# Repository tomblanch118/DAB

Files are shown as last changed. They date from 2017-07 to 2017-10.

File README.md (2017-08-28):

# DAB
Electronics schematics, mechanical design and code for the Defuse a Bomb team building activity.

## PCB Version 1.0
There are a few issues with the first version of the PCB, I used A7 and A6 for controlling the RGB LEDs and as the spare io pin. I missed the fact that these pins are analog inputs only (straight to the analog mux). As such version 1 of the pcb requires a few bodge wires from the icsp pins to the leds and buzzer to make it work. As the icsp pins are only used once to burn the bootloader this isnt really a problem and version 2 of the board will fix this. 

You can power the board from an ftdi cable/board however this results in backpowering the 5v regulator/no power to the 3.3v regulator. So far this hasnt proved to be a problem but it probably isnt ideal, YMMV. In future the 5v from the usb bus could be connected to vin but there is a good chance that the 5v regulators dropout voltage will mean that this wont work.

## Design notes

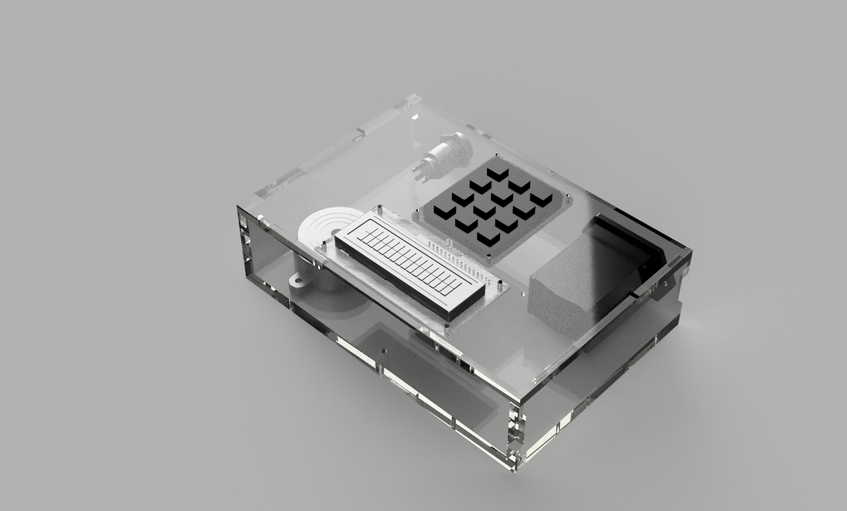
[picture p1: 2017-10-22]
model_render2.png

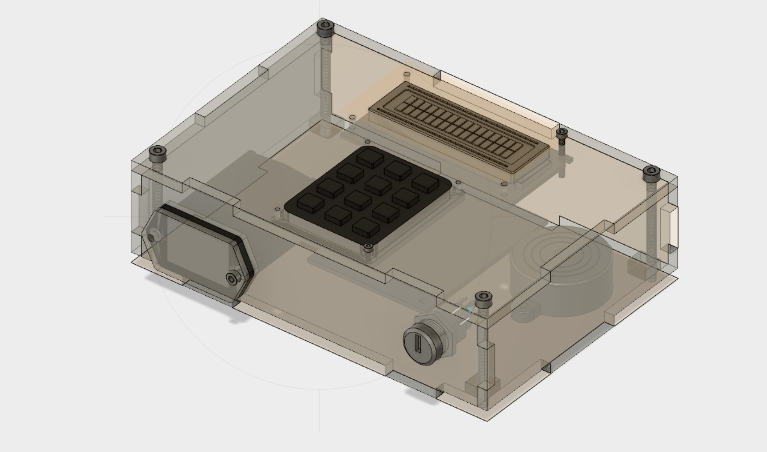
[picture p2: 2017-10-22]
model_view.png

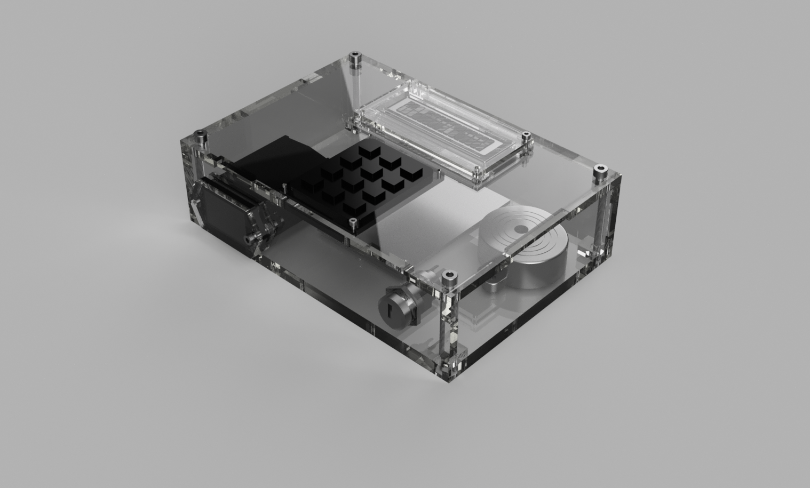
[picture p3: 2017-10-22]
model_render1.png

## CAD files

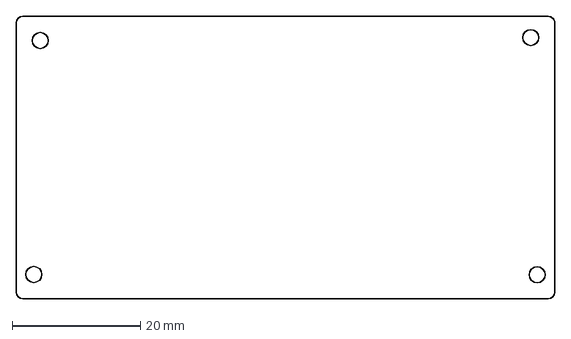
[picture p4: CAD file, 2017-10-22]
2D Designs/lcd_cover.dxf
84.0 x 44.0 mm

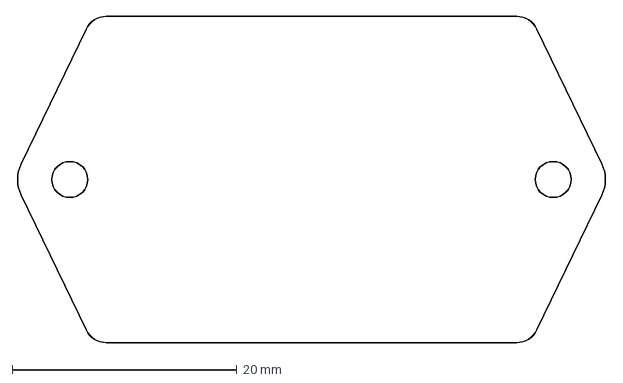
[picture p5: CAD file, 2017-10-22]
2D Designs/batt_cover.dxf
52.5 x 29.0 mm

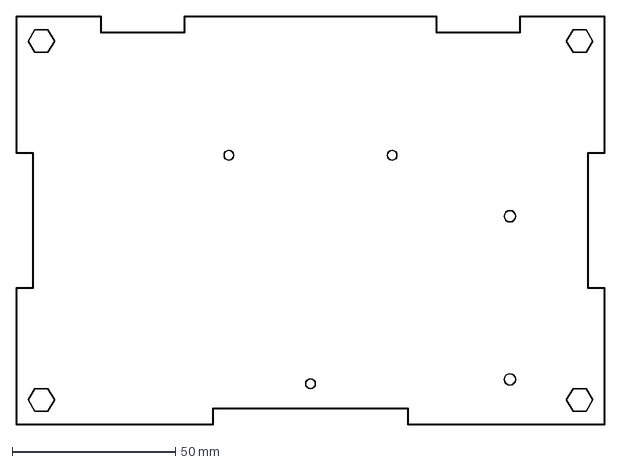
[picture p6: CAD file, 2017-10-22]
2D Designs/base.dxf
180.3 x 125.3 mm

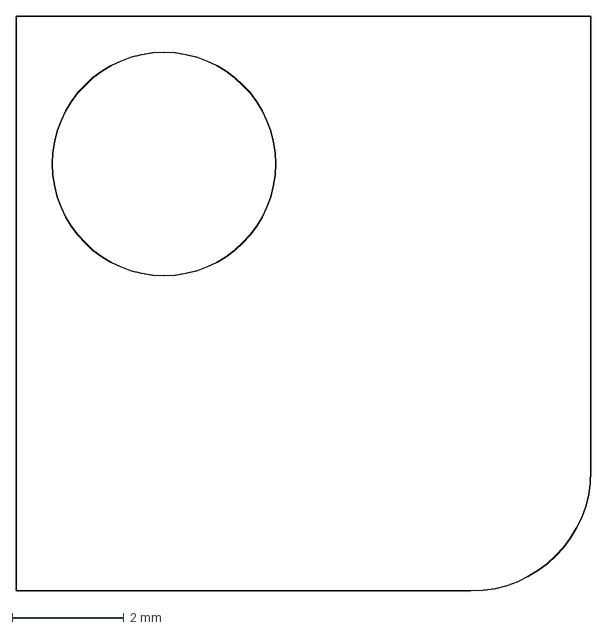
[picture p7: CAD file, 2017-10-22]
2D Designs/corner.dxf
10.3 x 10.3 mm

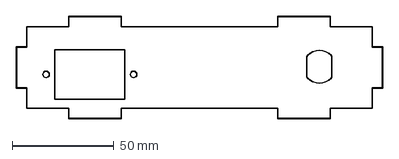
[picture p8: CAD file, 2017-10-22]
2D Designs/front.dxf
180.3 x 50.3 mm

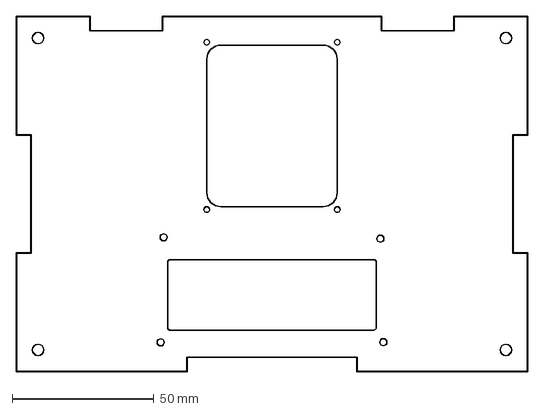
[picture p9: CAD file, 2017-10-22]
2D Designs/top.dxf
180.3 x 125.3 mm

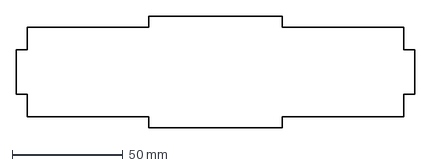
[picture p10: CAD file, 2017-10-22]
2D Designs/back.dxf
180.3 x 50.3 mm

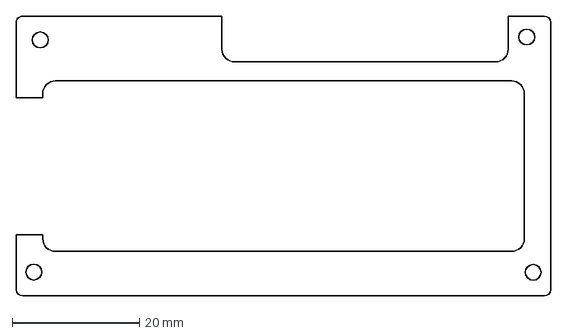
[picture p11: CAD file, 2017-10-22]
2D Designs/lcd_spacer.dxf
84.0 x 44.0 mm

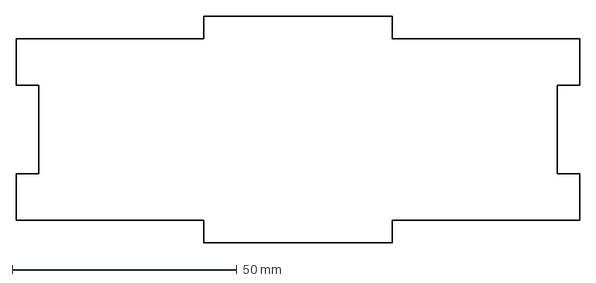
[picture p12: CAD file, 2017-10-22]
2D Designs/side.dxf
125.3 x 50.3 mm

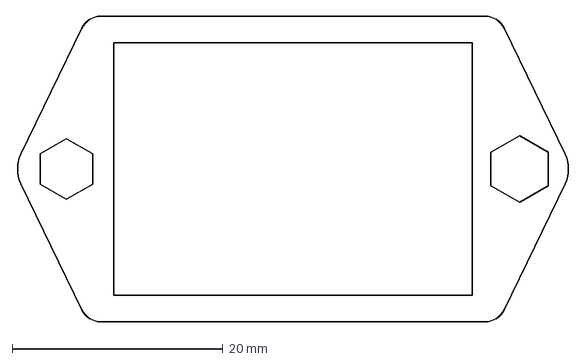
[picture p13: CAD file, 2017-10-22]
2D Designs/batt_bracker.dxf
52.5 x 29.0 mm

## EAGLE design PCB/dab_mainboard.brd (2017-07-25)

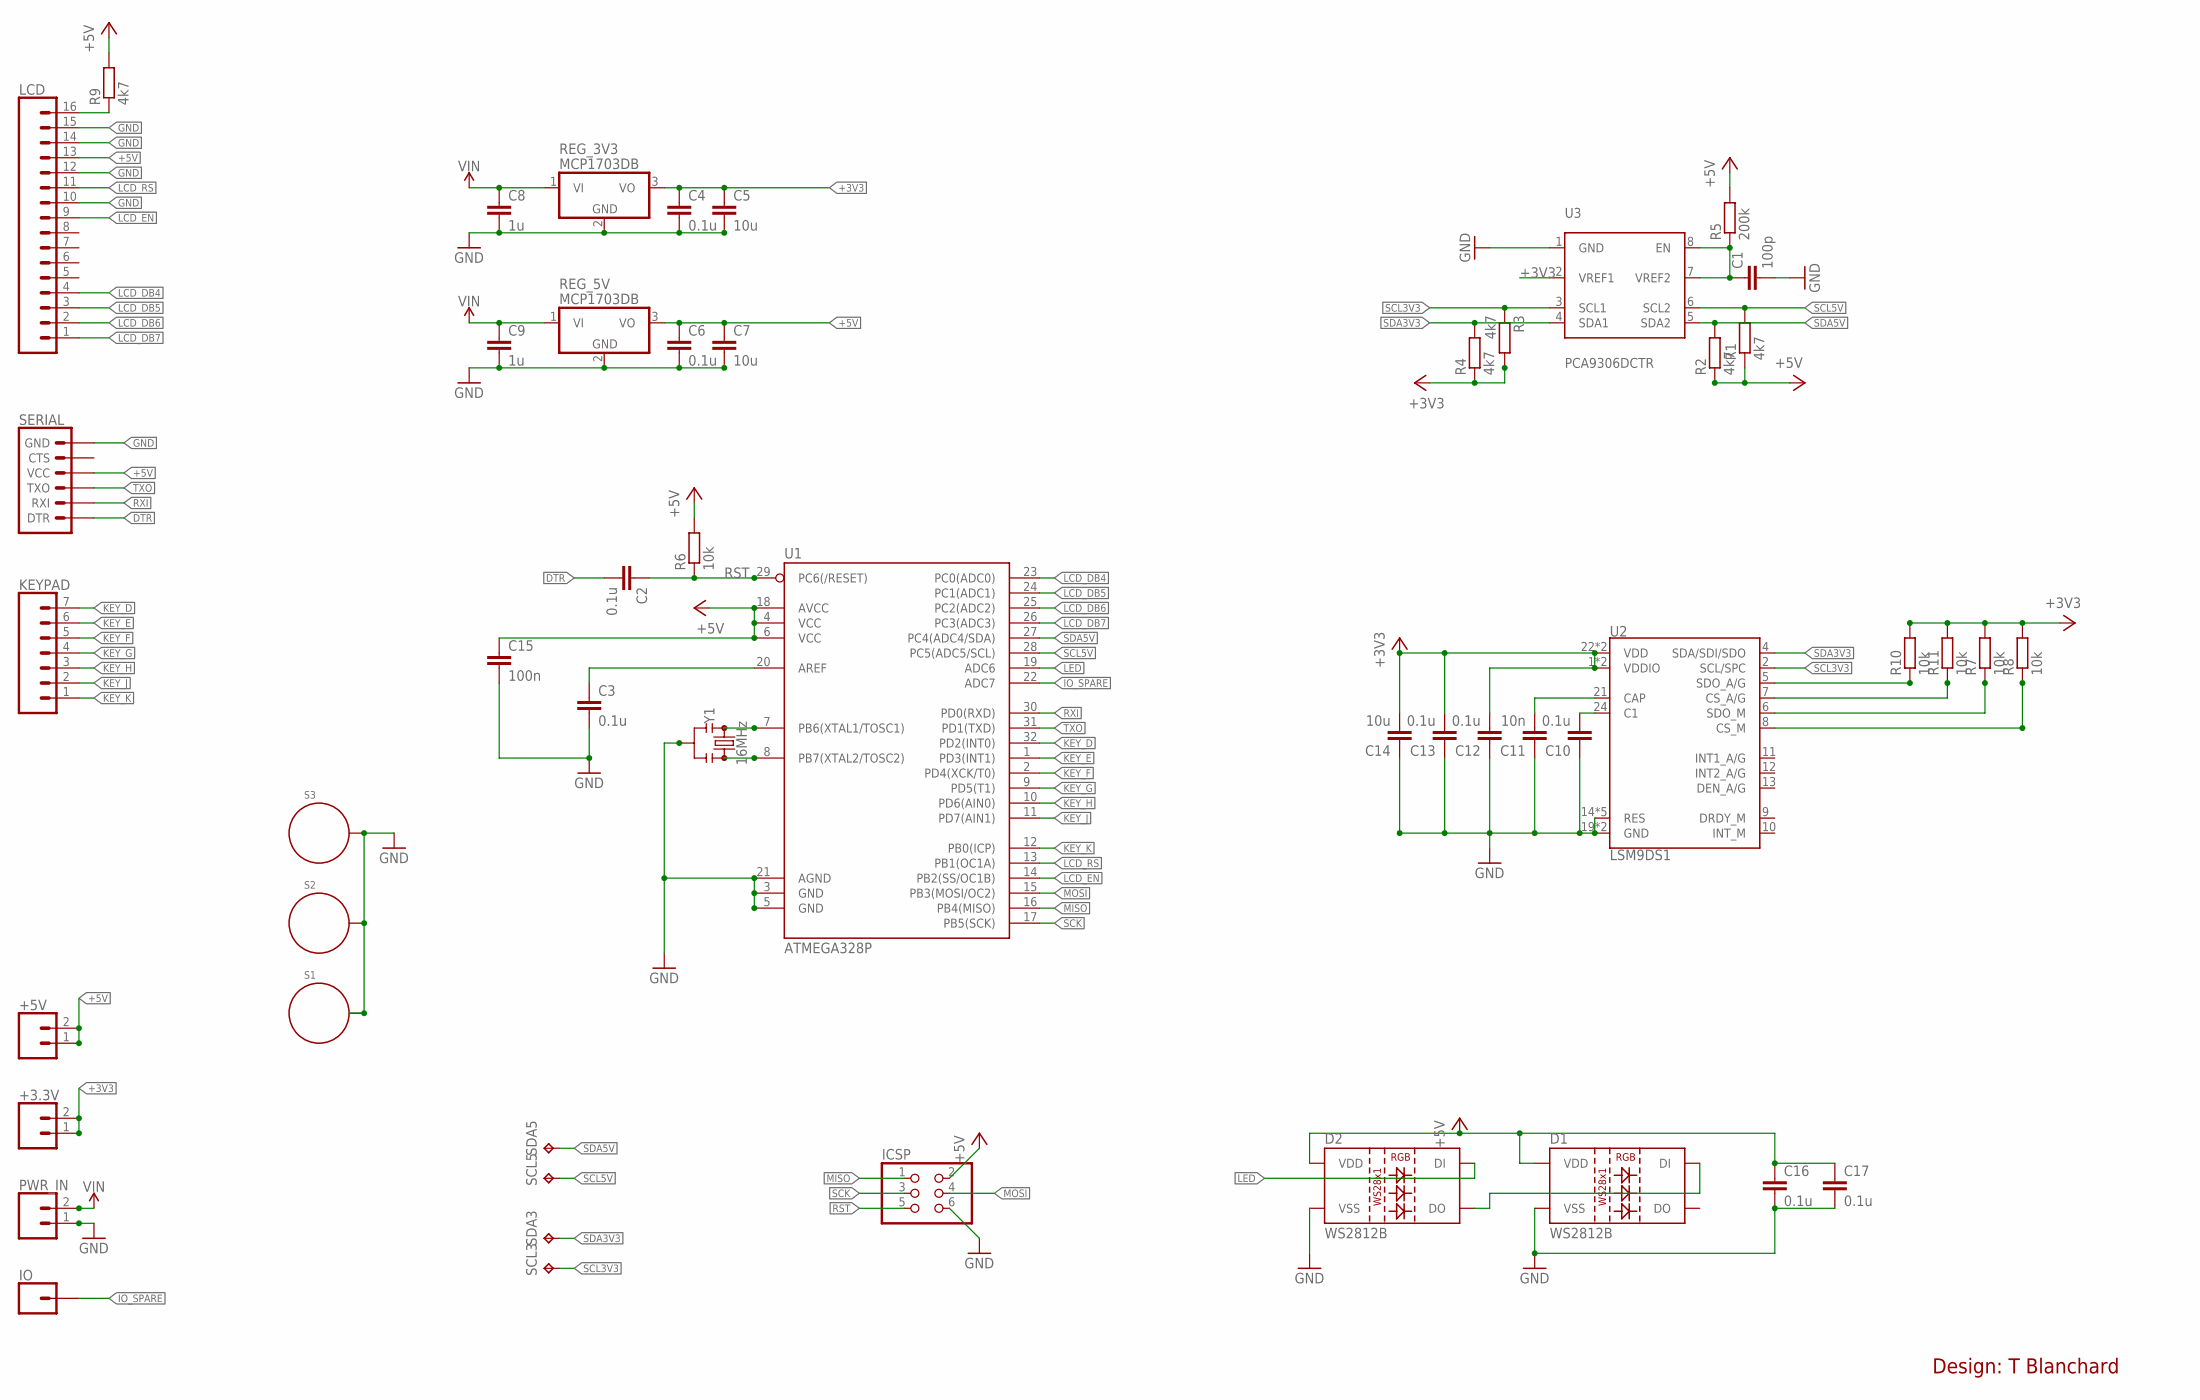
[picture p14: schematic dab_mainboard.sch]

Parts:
+3.3V, +5V: CONN_02; 1X02
C1: 100p; C0603
C2, C3, C4, C6, C10, C12, C13, C16, C17: 0.1u; C0603
C5, C7: 10u; C0805
C8, C9: 1u; C0603
C11: 10n; C0603
C14: 10u; C0603
C15: 100n; C0603
D1, D2: WS2812B
ICSP: PINHD-2X3; 2X03
IO: CONN_01; 1X01
KEYPAD: CONN_07; 1X07
LCD: CONN_16; 1X16
PWR_IN: CONN_02; 1X02
R1, R2, R3, R4, R9: 4k7; R0603
R5: 200k; R0603
R6, R7, R8, R10, R11: 10k; R0603
REG_3V3, REG_5V: MCP1703DB; SOT223
S1, S2, S3: STANDOFF_ELECTRICAL; STANDOFF-ELECTRICAL
SCL3, SCL5: TPTP08R; TP08R
SDA3, SDA5: TPTP08R; TP08R
SERIAL: 6_PIN_SERIAL_TARGETSILK; 6_PIN_SERIAL_TARGET_SIDE_W_SILK
U1: ATMEGA328P; TQFP32-08
U2: LSM9DS1; LGA-24-3.5X3
U3: PCA9306DCTR; SM8
Y1: 16MHz; RESONATOR-SMD-3.2X1.3

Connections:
+3V3: +3.3V.1, +3.3V.2, C4.1, C5.1, C12.2, C13.2, C14.2, R3.2, R4.1, R7.2, R8.2, R10.2, R11.2, REG_3V3.3 (VO), U2.1 (VDDIO), U2.3 (VDDIO), U2.22 (VDD), U2.23 (VDD), U3.2 (VREF1)
+5V: +5V.1, +5V.2, C6.1, C7.1, C15.1, C16.1, C17.1, D1.1 (VDD), D2.1 (VDD), ICSP.2, LCD.13, R1.1, R2.1, R5.2, R6.2, R9.2, REG_5V.3 (VO), SERIAL.P$4 (VCC), U1.4 (VCC), U1.6 (VCC), U1.18 (AVCC)
CS_M: R8.1, U2.8 (CS_M)
DTR: C2.2, SERIAL.P$1 (DTR)
GND: C1.2, C3.2, C4.2, C5.2, C6.2, C7.2, C8.2, C9.2, C10.1, C11.1, C12.1, C13.1, C14.1, C15.2, C16.2, C17.2, D1.3 (VSS), D2.3 (VSS), ICSP.6, LCD.10, LCD.12, LCD.14, LCD.15, PWR_IN.1, REG_3V3.2 (GND), REG_5V.2 (GND), S1.P1, S2.P1, S3.P1, SERIAL.P$6 (GND), U1.3 (GND), U1.5 (GND), U1.21 (AGND), U2.14 (RES), U2.15 (RES), U2.16 (RES), U2.17 (RES), U2.18 (RES), U2.19 (GND), U2.20 (GND), U3.1 (GND), Y1.2
IO_SPARE: IO.1, U1.22 (ADC7)
KEY_D: KEYPAD.7, U1.32 (PD2(INT0))
KEY_E: KEYPAD.6, U1.1 (PD3(INT1))
KEY_F: KEYPAD.5, U1.2 (PD4(XCK/T0))
KEY_G: KEYPAD.4, U1.9 (PD5(T1))
KEY_H: KEYPAD.3, U1.10 (PD6(AIN0))
KEY_J: KEYPAD.2, U1.11 (PD7(AIN1))
KEY_K: KEYPAD.1, U1.12 (PB0(ICP))
LCD_DB4: LCD.4, U1.23 (PC0(ADC0))
LCD_DB5: LCD.3, U1.24 (PC1(ADC1))
LCD_DB6: LCD.2, U1.25 (PC2(ADC2))
LCD_DB7: LCD.1, U1.26 (PC3(ADC3))
LCD_EN: LCD.9, U1.14 (PB2(SS/OC1B))
LCD_RS: LCD.11, U1.13 (PB1(OC1A))
LED: D2.4 (DI), U1.19 (ADC6)
MISO: ICSP.1, U1.16 (PB4(MISO))
MOSI: ICSP.4, U1.15 (PB3(MOSI/OC2))
unnamed: C1.1, R5.1, U3.7 (VREF2), U3.8 (EN)
unnamed: U1.7 (PB6(XTAL1/TOSC1)), Y1.1
unnamed: U1.8 (PB7(XTAL2/TOSC2)), Y1.3
unnamed: R7.1, U2.6 (SDO_M)
unnamed: C3.1, U1.20 (AREF)
unnamed: R11.1, U2.7 (CS_A/G)
unnamed: R10.1, U2.5 (SDO_A/G)
unnamed: LCD.16, R9.1
unnamed: C10.2, U2.24 (C1)
unnamed: C11.2, U2.21 (CAP)
unnamed: D1.4 (DI), D2.2 (DO)
RST: C2.1, ICSP.5, R6.1, U1.29 (PC6(/RESET))
RXI: SERIAL.P$3 (RXI), U1.30 (PD0(RXD))
SCK: ICSP.3, U1.17 (PB5(SCK))
SCL3V3: R3.1, SCL3.TP, U2.2 (SCL/SPC), U3.3 (SCL1)
SCL5V: R1.2, SCL5.TP, U1.28 (PC5(ADC5/SCL)), U3.6 (SCL2)
SDA3V3: R4.2, SDA3.TP, U2.4 (SDA/SDI/SDO), U3.4 (SDA1)
SDA5V: R2.2, SDA5.TP, U1.27 (PC4(ADC4/SDA)), U3.5 (SDA2)
TXO: SERIAL.P$2 (TXO), U1.31 (PD1(TXD))
VIN: C8.1, C9.1, PWR_IN.2, REG_3V3.1 (VI), REG_5V.1 (VI)

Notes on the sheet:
Design: T Blanchard

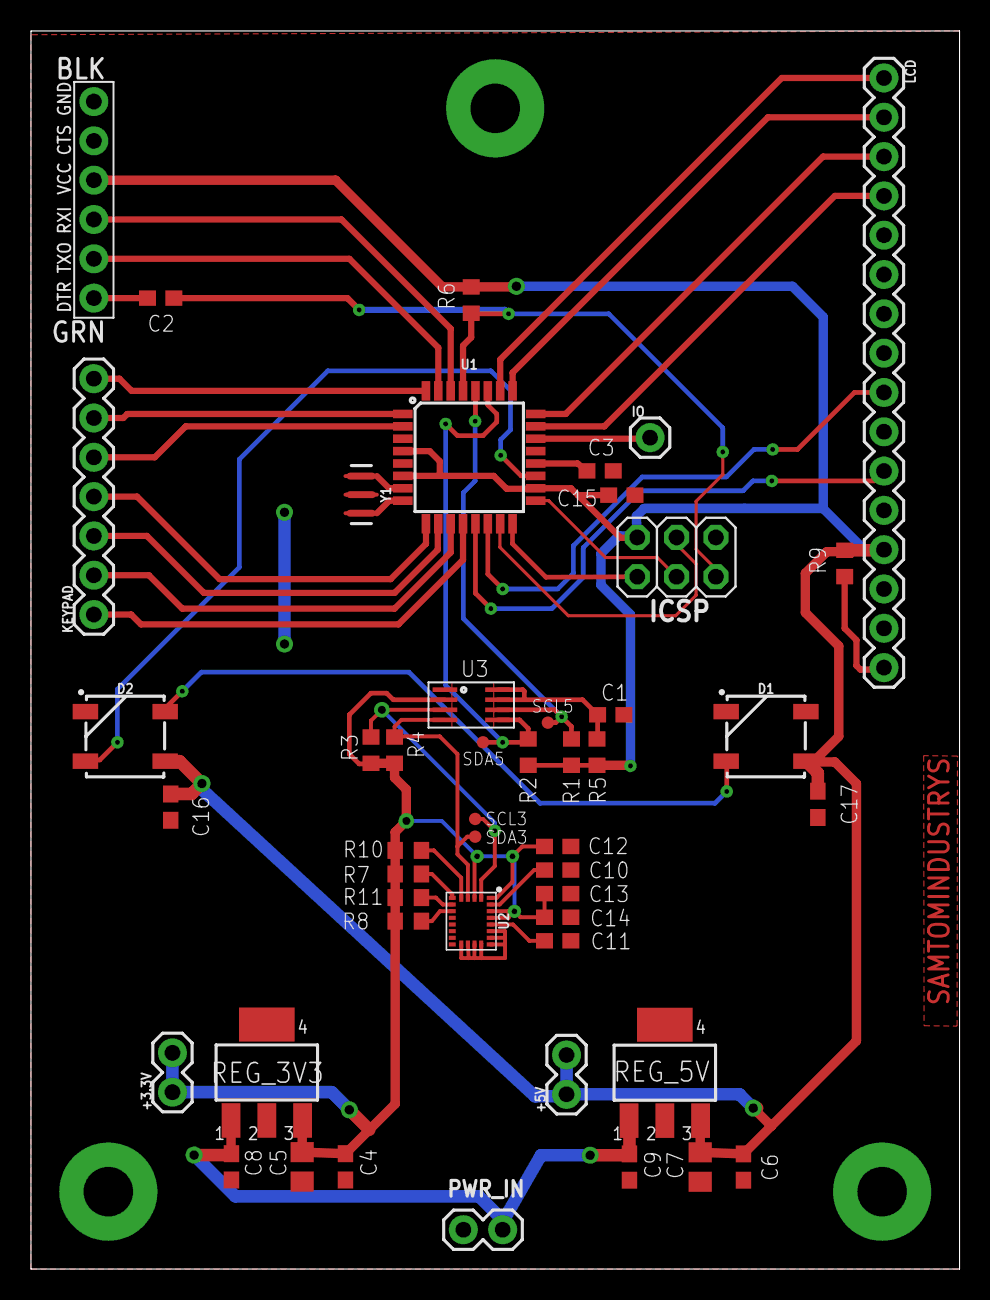
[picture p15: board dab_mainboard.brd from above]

Board: 2 copper layers, 60.0 x 80.0 mm, 51 parts (0 on the bottom side), 42 nets.

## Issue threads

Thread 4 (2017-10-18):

Make sure defuse button doesnt collide with resetting

tomblanch118, 2017-10-18:
The # key is both the reset mechanism and a possible defuse key. Occasionally this can cause problems.

Closed 2018-10-09.

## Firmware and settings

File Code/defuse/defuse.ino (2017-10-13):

/**
 * Project: Defuse a Bomb Teambuilding Activity
 * Author: Tom Blanchard 
 * Date: 10/10/2017
 * Version: 1
 * Revisions:
 */
#include <LiquidCrystal.h>
#include <Wire.h>
#include <SPI.h>
#include <SparkFunLSM9DS1.h>
#include <Keypad.h>
#include <Adafruit_NeoPixel.h>
#include <EEPROM.h>
#include "defuse.h"

#define EEPROM_TIME_ADDR 0x00
#define EEPROM_SENSITIVITY_ADDR 0x01
// SDO_XM and SDO_G are both pulled high, so our addresses are:
#define LSM9DS1_M  0x1E // Would be 0x1C if SDO_M is LOW
#define LSM9DS1_AG  0x6B // Would be 0x6A if SDO_AG is LOW
//Neopixel pin
#define LED_PIN 11
#define BUZZ_PIN 13

#define DEFUSE_TIME 90

Adafruit_NeoPixel strip = Adafruit_NeoPixel(2, LED_PIN, NEO_GRB + NEO_KHZ800);
// initialize the library with the numbers of the interface pins
LiquidCrystal lcd(9, 10, A0, A1, A2, A3); // A3, A2, A1, A0);

LSM9DS1 imu;


volatile boolean timer_tick = false;

double base_x = 0;
double base_y = 0;
double base_z = 0;

uint8_t code = 0;
uint8_t solution = 0;

byte rowPins[ROWS] = {8, 7, 6, 5}; //connect to the row pinouts of the kpd
byte colPins[COLS] = {4, 3, 2}; //connect to the column pinouts of the kpd
Keypad keypad = Keypad( makeKeymap(keys), rowPins, colPins, ROWS, COLS );


uint8_t mask_index = 0;
uint8_t op_index = 0;
uint8_t beep_index = 0;

volatile long time_limit = 0;
long sensitivity = 0;
boolean beeping = false;
volatile uint8_t beep_count = 0;
volatile BeepMode bmode = NORMAL;

void setup() {
  //Set pins
  pinMode(BUZZ_PIN, OUTPUT);
  digitalWrite(BUZZ_PIN, LOW);

  // set up the LCD's number of columns and rows:
  Serial.begin(115200);

  lcd.begin(16, 2);
  lcd.clear();


  imu.settings.device.commInterface = IMU_MODE_I2C;
  imu.settings.device.mAddress = LSM9DS1_M;
  imu.settings.device.agAddress = LSM9DS1_AG;
  // The above lines will only take effect AFTER calling
  // imu.begin(), which verifies communication with the IMU
  // and turns it on

  if (!imu.begin())
  {
    lcd.print("IMU err");
    Serial.println("Failed to communicate with LSM9DS1.");
    while (1);
  }
  else {
    lcd.print("IMU init");
  }

  // Initialize all pixels to 'off'
  strip.begin();
  strip.show();

  //Show settings menu
  lcd.clear();
  lcd.print("* Settings");
  lcd.setCursor(0, 1);
  lcd.print("# Start");

  //Wait for user to press button
  while (1)
  {
    keypad.getKeys();
    if (keypad.isPressed('*'))
    {
      //Allow user to get their hands onto the buttons
      check_settings(true);
      break;
    }
    if ( keypad.isPressed('#'))
    {
      check_settings(false);
      break;
    }
  }

  //Seed the random number generator
  randomSeed(millis());
  code = (uint8_t)random(255);
  mask_index = random(sizeof(masks) / sizeof(mask_profile));
  op_index = random(sizeof(ops) / sizeof(op_profile));
  beep_index = random(sizeof(beeps) / sizeof(beep_profile));

  //Precalc the solution
  solution = process_code();

  //Show the code/solution
  lcd.clear();
  lcd.print("Num:");
  lcd.print(code);
  lcd.setCursor(0, 1);
  lcd.print("Passwd:");
  lcd.print(solution);
  lcd.print(" B:");
  lcd.print(beeps[beep_index].defuse_key);

  //Determine the interval for beeping
  beep_count = beeps[beep_index].interval - 1;

  //Show the led colors
  strip.setPixelColor(0, strip.Color(masks[mask_index].r, masks[mask_index].g, masks[mask_index].b));
  strip.setPixelColor(1, strip.Color(ops[op_index].r, ops[op_index].g, ops[op_index].b));
  strip.show();


  //Wait for # to continue
  delay(1000);
  while (1)
  {
    keypad.getKeys();
    if (keypad.isPressed('#'))
    {
      break;
    }
  }

  //Get calibration
  get_calibration();

  //Clear Leds
  setLedsToColor(0, 0, 0);

  //Start the timer and timer interrupts
  init_timer1();

}

char topbuff[17] = {'\0'};


void loop() {

  //Get the time at the start of the loop
  unsigned long loop_start = millis();


  //******************************
  //DETECT IF OUT OF TIME
  if (time_limit <= 0)
  {
    boom(TIME);
  }

  //*******************************
  //DETECT IF DEFUSED
  //Get all keypresses
  if (keypad.getKeys())
  {
    for (int i = 0; i < LIST_MAX; i++) // Scan the whole key list.
    {
      //check it is in a pressed state
      if (keypad.key[i].kstate == PRESSED)
      {
        //see if it is the correct button
        if (keypad.key[i].kchar == beeps[beep_index].defuse_key)
        {
          //Move on to defusing
          defuse();
        }
        else {

          sprintf(topbuff, "%s", "INCORRECT BUTTON");
          if (time_limit > 10)
          {
            time_limit = 10;
          }
          digitalWrite(BUZZ_PIN, HIGH);
        }

      }
    }
  }


  //****************************
  //DETECT GONE OFF
  //Get more accelerometer data
  if ( imu.accelAvailable() )
  {
    imu.readAccel();

    //Correct based on calibration
    int err_x = abs(base_x - imu.ax);
    int err_y = abs(base_y - imu.ay);
    int err_z = abs(base_z - imu.az);

    //TODO: find decent threshold
    if ( (err_x > sensitivity) || (err_y > sensitivity) || (err_z > 2 * sensitivity) )
    {
      Serial.print(err_x);
      Serial.print(", ");
      Serial.print(err_y);
      Serial.print(", ");
      Serial.println(err_z);
      boom(MOTION);
    }
  }

  if (timer_tick)
  {
    do_time();
  }

  //keep the loop to approx 20 msec
  unsigned long loop_end = millis();
  unsigned long diff = loop_end - loop_start;

  if (diff > 20)
  {
    diff = 20;
  }
  delay(20 - diff);
}

/**
   Processes the code generated and returns the solution the user must type in to defuse the bomb
*/
uint8_t process_code()
{
  CodeOperator op = ops[op_index].op;
  uint8_t mask = masks[mask_index].mask;

  uint8_t processed_code = 0;
  Serial.println(code);

  //Perform operation using mask
  switch (op)
  {
    case NOT:
      Serial.println("NOT");
      processed_code  = ~code;// | mask;
      break;
    case AND:
      Serial.println("AND");
      processed_code  = code & mask;
      break;
    case OR:
      Serial.println("OR");
      processed_code  = code | mask;
      break;
    case XOR:
      Serial.println("XOR");
      processed_code  = code ^ mask;
      break;
    default:
      Serial.println("Err in processing code");
  }
  Serial.println(mask, BIN);
  Serial.println(processed_code);
  return processed_code;
}

void defuse()
{
  bmode = TIMEBASED;
  beep_count = 0;
  topbuff[0] = '\0';
  digitalWrite(BUZZ_PIN, LOW);
  strip.setPixelColor(0, strip.Color(masks[mask_index].r, masks[mask_index].g, masks[mask_index].b));
  strip.setPixelColor(1, strip.Color(ops[op_index].r, ops[op_index].g, ops[op_index].b));
  strip.show();


  time_limit = DEFUSE_TIME;

  lcd.clear();
  lcd.setCursor(0, 0);
  lcd.print("MOTION DISABLED");

  delay(1000);

  lcd.clear();
  uint8_t pos = 0;

  while (1) {
    if (time_limit < 0)
    {
      boom(DEFUSEFAIL);
    }
    if (timer_tick)
    {
      do_time();
    }
    char key = keypad.getKey();

    if (key == '*')
    {
      topbuff[pos] = '\0';
      long entered_code = atol(topbuff);
      if (entered_code > 255)
      {
        Serial.println("Value larger than uint8_t");
      }


      if ((long)solution == entered_code)
      {
        Serial.println("Welldone");
        boom_success();
      }
      else
      {
        Serial.println("Woops");
        Serial.println(solution);
        Serial.println(entered_code);
        lcd.clear();
        lcd.setCursor(0,1);
        lcd.println("     WRONG!     ");
        pos = 0;
        topbuff[pos] = '\0';
        delay(2000);
      }
      do_time();
      continue;
    }

    if (key == '#')
    {
      pos = 0;
      topbuff[pos] = '\0';
      do_time();
      continue;
    }

    if (key) {
      topbuff[pos] = key;
      pos++;
      topbuff[pos] = '\0';

      if (pos >= 10)
      {
        pos = 0;
      }
      do_time();
    }

  }
}

void boom_success()
{
  bmode = STOP;
  setLedsToColor(0, 255, 0);
  lcd.clear();
  lcd.setCursor(0, 0);
  lcd.print("  -=YOU WIN!=-");
  lcd.setCursor(0, 1);
  lcd.print(" -=WELL DONE!=-");

  while (1);

  //TODO: something fun here? rgb lights and a tune?
}

void boom(BoomReason br)
{
  lcd.clear();
  lcd.setCursor(0, 0);
  lcd.print("    -=BOOM=-");
  lcd.setCursor(0, 1);
  lcd.print("  GAME IS OVER");
  BeepMode prev_bmode = bmode;
  bmode = STOP;
  digitalWrite(BUZZ_PIN, HIGH);


  setLedsToColor(255, 0, 0);
  boolean booming = true;
  while (booming)
  {
    keypad.getKeys();

    if ( (time_limit > 0 ) && (br == MOTION) && (keypad.isPressed('#')) ) {
      bmode = prev_bmode;
      digitalWrite(BUZZ_PIN, LOW);
      setLedsToColor(0, 0, 0);
      get_calibration();
      break;
    }
    if (keypad.isPressed('#'))
    {
      digitalWrite(BUZZ_PIN, LOW);
    }

  }
}

void check_settings(boolean change)
{

  //Read set time in minutes and sensitivity from eeprom
  time_limit = EEPROM.read(EEPROM_TIME_ADDR);
  sensitivity = EEPROM.read(EEPROM_SENSITIVITY_ADDR);


  if (change)
  {

    Serial.println("Settings Menu");

    Serial.println(time_limit);
    Serial.println(sensitivity);
    uint8_t ptl = 0;
    uint8_t psn = 0;

    uint8_t sn = sensitivity;
    uint8_t tl = time_limit;

    while (!keypad.isPressed('#'))
    {
      keypad.getKeys();

      if (keypad.isPressed('1'))
      {
        tl--;
      }
      if (keypad.isPressed('3'))
      {
        tl++;
      }
      if (keypad.isPressed('4'))
      {
        sn--;
      }
      if (keypad.isPressed('6'))
      {
        sn++;
      }

      if ( (ptl != tl) || (psn != sn))  {
        lcd.clear();
        lcd.setCursor(0, 0);
        lcd.print("Time:");
        lcd.print(tl);
        lcd.print("mins");
        lcd.setCursor(0, 1);
        lcd.print("Sensivity:");
        lcd.print(sn);
      }
      ptl = tl;
      psn = sn;
      delay(50);
    }
    Serial.println("New Settings");
    lcd.clear();
    lcd.setCursor(0, 0);
    lcd.print("Saved");
    EEPROM.write(EEPROM_TIME_ADDR, tl);
    EEPROM.write(EEPROM_SENSITIVITY_ADDR, sn);
    time_limit = tl;
    sensitivity = sn;
    delay(1000);
  }

  time_limit = time_limit * 60; //scale to seconds
  sensitivity  = sensitivity * 10; //scale up to better range
}

void get_calibration()
{
  lcd.clear();
  lcd.setCursor(0, 0);
  lcd.print("Calibrating...");
  lcd.setCursor(0, 1);
  lcd.print("Keep Still");
  delay(1000);
  for (int i = 0; i < 50; i++)
  {
    if ( imu.accelAvailable() )
    {
      imu.readAccel();
      base_x = ( 0.5f * base_x ) + (0.5f * imu.ax);
      base_y = ( 0.5f * base_y ) + (0.5f * imu.ay);
      base_z = ( 0.5f * base_z ) + (0.5f * imu.az);
    }
    delay(20);
  }

  Serial.println(base_x);
  Serial.println(base_y);
  Serial.println(base_z);
}

static void setLedsToColor(uint8_t r, uint8_t g, uint8_t b)
{

  for (int i = 0; i < strip.numPixels(); i++) {
    strip.setPixelColor(i, strip.Color(r, g, b));
  }
  strip.show();
}

static inline void init_timer1()
{
  //Set counter to 0
  TCNT1 = 0;

  //Set to CTC mode, 64 prescaler
  TCCR1A = 0x00;
  TCCR1B = _BV(WGM12) | _BV(CS11) | _BV(CS10);

  //16,000,000 MHz / 64 = 2500,00
  //Set output compare for 1/10 second interrupt this is scaled to 1Hz by the interrupt handler
  OCR1A = 2500;//15625;
  //This means we can do things (like beep annoyingly) at 4/5Hz


  //turn on output compare 1 A interrupt
  TIMSK1 |= _BV(OCIE1A);

  //Make sure interrupts are on
  sei();
}


ISR(TIMER1_COMPA_vect)
{
  static uint8_t time_speed = 100;
  time_speed--;
  if (time_speed == 0)
  {
    time_speed = 100;
    timer_tick = true;

    time_limit--;

    //This is the regular beep method
    if (bmode == NORMAL) {
      //If it is time to beep
      if (beep_count == 0) {
        //If we are already beeping, stop and reset
        if (beeping) {
          beep_count = beeps[beep_index].interval - 1;
          beeping = false;
          digitalWrite(BUZZ_PIN, LOW);
        }
        else {//otherwise start beeping
          beeping = true;
          digitalWrite(BUZZ_PIN, HIGH);
        }
      }
      else {
        beep_count--;
      }
    }
  }

  if (bmode == TIMEBASED) {
    if (beep_count == 0) {
      //If we are already beeping, stop and reset
      if (beeping) {
        long working_time = time_limit;
        if (working_time >= DEFUSE_TIME) {
          working_time = DEFUSE_TIME;
        }

        beep_count = map(working_time, DEFUSE_TIME, 0, 100, 0);

        beeping = false;
        digitalWrite(BUZZ_PIN, LOW);
      }
      else {//otherwise start beeping
        beeping = true;
        digitalWrite(BUZZ_PIN, HIGH);
      }
    }
    else {
      beep_count--;
    }
  }
}

static void do_time()
{
  timer_tick = false;

  lcd.clear();
  lcd.setCursor(0, 1);
  lcd.print(topbuff);
  lcd.setCursor(6, 0);
  if ((time_limit / 60) < 10)
  {
    lcd.print("0");
  }
  lcd.print((time_limit / 60));
  lcd.print(":");
  if ((time_limit % 60) < 10)
  {
    lcd.print("0");
  }
  lcd.print((time_limit % 60));

}

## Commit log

2017-07-06 Defuse A Bomb Game
    Code and pcb/schematics for the Defuse A Bomb Gregynog Game.
    [dab_mainboard.brd, dab_mainboard.sch]
2017-07-25 Version 1 Final
    [dab_mainboard.brd, dab_mainboard.sch]
2017-10-13 Added V1 Code
    Working version of the code. Uses keypad,lcd, buzzer, accelerometer and
    leds.
    [defuse.ino]
2017-10-22 Added 2d design files
    Moved eagle pcb files and added 2d designs suitable for laser cutting.
    [back.dxf, base.dxf, batt_bracker.dxf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]
2018-10-09 Settings change
    Changed one of the motion sensor disable buttons from # to 7 so that it doesn't clash with the resetting the bomb .

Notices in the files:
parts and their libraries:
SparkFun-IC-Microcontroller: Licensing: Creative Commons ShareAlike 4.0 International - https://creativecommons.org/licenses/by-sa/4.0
